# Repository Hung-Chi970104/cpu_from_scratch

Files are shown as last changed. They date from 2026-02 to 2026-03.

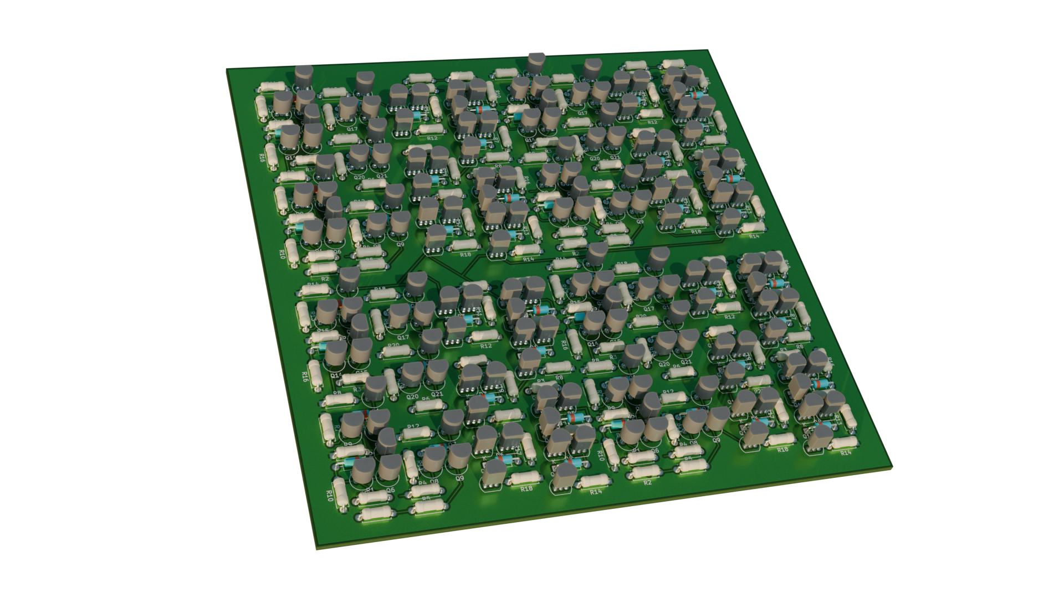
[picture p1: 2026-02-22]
assets/cpu.png

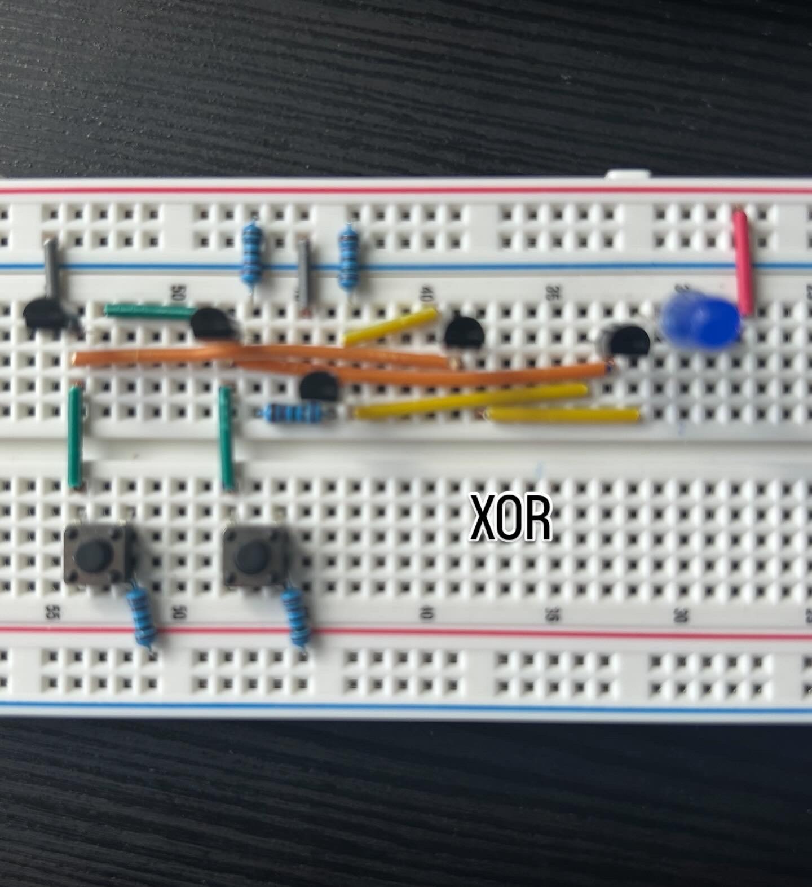
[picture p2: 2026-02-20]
assets/XOR.JPG

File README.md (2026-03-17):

## Hardware Specifications & Bill of Materials (BOM)
*** Sry this board is still in production but I'll reship it once it's delivered!!!

This project is inspired by Hyperspace Pirate: https://youtu.be/X31B1pVow1o?si=pDOqtu37fK6EBQ2z

cpu
This DIY 4-but CPU uses BJT logic to build various logic gates, while using discrete NPN transistors as saturated switches

| Component Class | Specification / Part Number | Function |
| --- | --- | --- |
| **Active Switching** | 2N3904 (NPN BJT) | Core logic gates (amplification and switching) |
| **Passive Routing** | Standard Rectifier Diodes | Signal isolation and OR-tie routing |
| **Pull-up/Pull-down** | 10kΩ Resistors | Ensuring definitive HIGH/LOW logic states |
| **Base Biasing** | 4.7kΩ Resistors | Base current limiting to prevent thermal runaway |
| **Current Limiting** | 1kΩ Resistors | Collector current limiting |

---

## Schematic Design

The architecture has both **SUM** and **CARRY (Cout)** logic using fundamental logic gates built from scratch
adder

### Logic Gate Topologies

The computational core relies on three primary gate topologies designed from discrete NPN transistors:

1. **NAND Gate:** Series-connected BJTs requiring all inputs to be HIGH to pull the output LOW
2. **NOR Gate:** Parallel-connected BJTs where any HIGH input pulls the output LOW
3. **XOR Gate:** A composite gate critical for the SUM generation

*Gate Implementation Reference:*

* [XOR Gate Schematic](https://github.com/user-attachments/assets/9e057bf3-4b33-4ee1-a783-3fd075c37234)
* [NOR Gate Schematic](https://github.com/user-attachments/assets/835cebbe-9da9-4931-9af1-0fc856e21aca)
* [NAND Gate Schematic](https://github.com/user-attachments/assets/38a2fae2-0add-45c0-82a7-d2f594ea8222)

---

## Validation Using Truth Table

The circuit has been validated against the standard 1-bit full adder truth table, successfully transitioning between all 8 states cleanly:

| Input A | Input B | Carry In (Cin) | SUM Output | Carry Out (Cout) |
| --- | --- | --- | --- | --- |
| 0 | 0 | 0 | **0** | **0** |
| 0 | 0 | 1 | **1** | **0** |
| 0 | 1 | 0 | **1** | **0** |
| 0 | 1 | 1 | **0** | **1** |
| 1 | 0 | 0 | **1** | **0** |
| 1 | 0 | 1 | **0** | **1** |
| 1 | 1 | 0 | **0** | **1** |
| 1 | 1 | 1 | **1** | **1** |

---

## Technical Challenges

To build this, I was forced to learn many things that I hadn't even seen before, such as truth table and logic gates. Truth table is the foundation of computing logic, while logic gates are the way to implement the the logic

* **Fan-Out Limitations & Signal Integrity:** Driving multiple inputs from a single output stage caused severe voltage drops. This required very careful pull-up and base resistor values to ensure subsequent transistor stages have adequate saturation current without dragging the logic HIGH state into the regions that should be low
* **XOR Current Starvation:** The initial Exclusive-OR (XOR) architecture failed due to a topology that tried to drive two separate transistor bases from a single unbuffered node. And this caused current to split in two parallel streams, preventing either transistor from fully switching

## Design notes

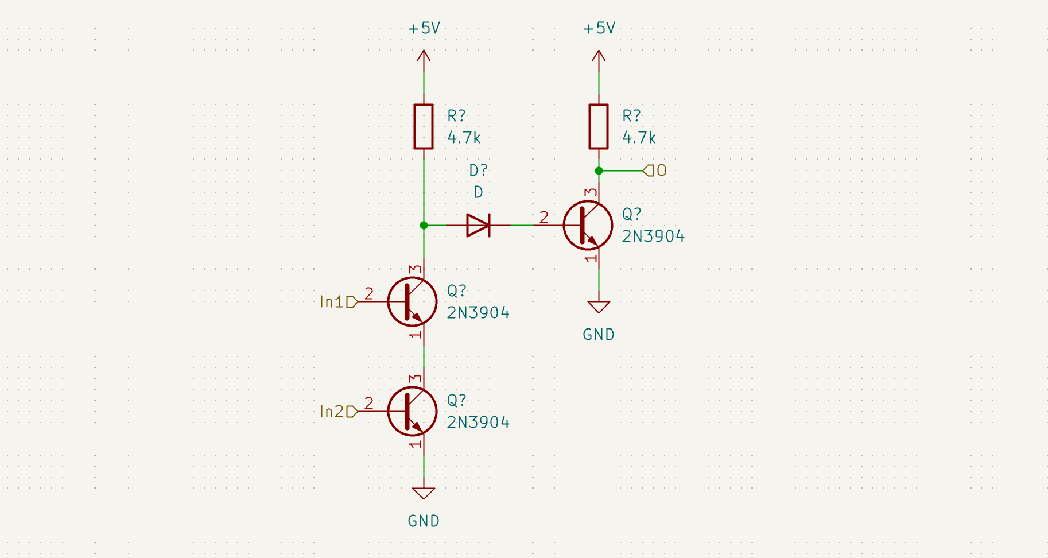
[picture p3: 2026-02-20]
assets/and.png

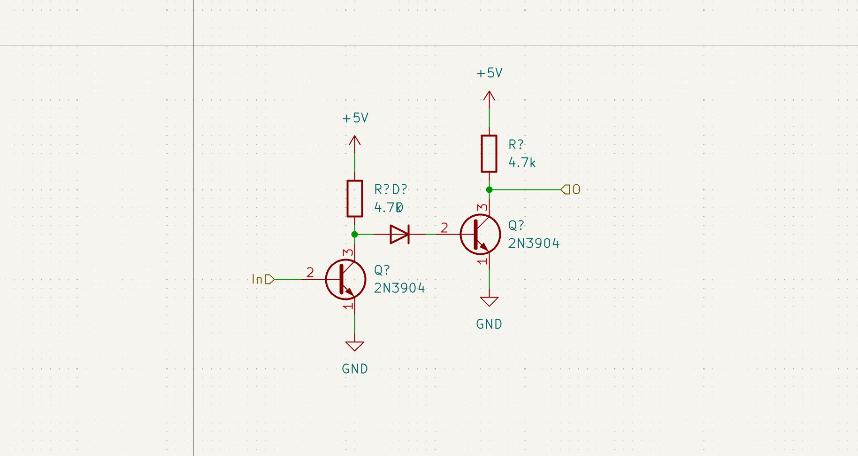
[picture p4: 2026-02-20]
assets/or.png

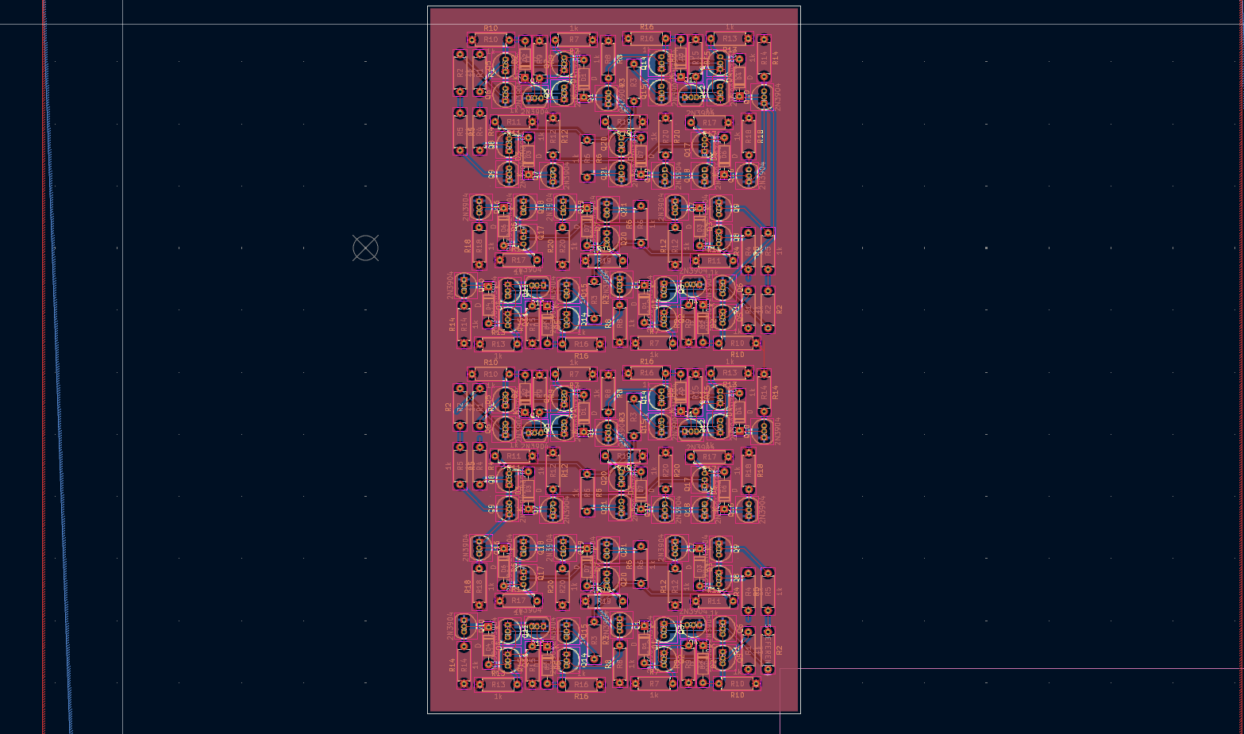
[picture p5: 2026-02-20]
assets/pcb.png

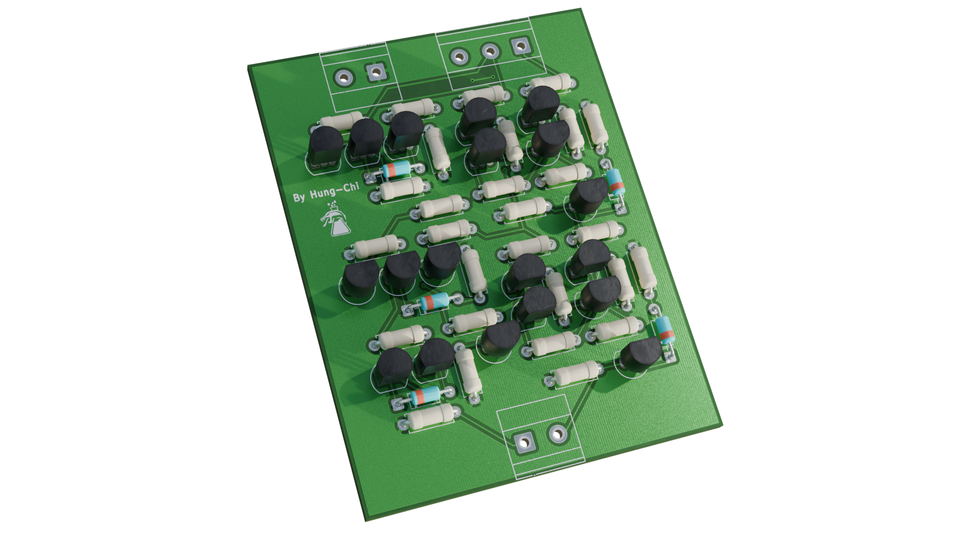
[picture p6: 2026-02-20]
assets/1_bit_adder.png

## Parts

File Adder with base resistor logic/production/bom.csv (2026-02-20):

Designator | Footprint | Quantity | Value | LCSC Part #
D1, D3, D5, D6, D8 | D_DO-35_SOD27_P7.62mm_Horizontal | 5 | D
J1, J3 | TerminalBlock_Phoenix_MKDS-1,5-2-5.08_1x02_P5.08mm_Horizontal | 2 | Screw_Terminal_01x02
J2 | TerminalBlock_Phoenix_MKDS-1,5-3-5.08_1x03_P5.08mm_Horizontal | 1 | Screw_Terminal_01x03
Q1, Q11, Q12, Q13, Q17, Q18, Q19, Q2, Q20, Q26, Q27, Q28, Q29, Q3, Q30, Q4, Q5, Q6, Q7 | TO-92_Inline | 19 | 2N3904
R1, R2, R23, R24, R25, R26, R27, R28, R29, R3, R30, R31, R32, R33, R34, R4, R43, R44, R45, R46, R47, R48, R49, R5, R50, R6, R7, R8 | R_Axial_DIN0207_L6.3mm_D2.5mm_P7.62mm_Horizontal | 28 | 4.7k

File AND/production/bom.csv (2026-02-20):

Designator | Footprint | Quantity | Value | LCSC Part #
D1 | D_DO-35_SOD27_P7.62mm_Horizontal | 1 | D
J1, J2 | PinHeader_1x03_P2.54mm_Vertical | 2 | Conn_01x03
Q1, Q2, Q3 | TO-92_Inline | 3 | 2N3904
R1, R2, R3, R4 | R_Axial_DIN0207_L6.3mm_D2.5mm_P7.62mm_Horizontal | 4 | 4.7k

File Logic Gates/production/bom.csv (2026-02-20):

Designator | Footprint | Quantity | Value | LCSC Part #
D1, D2, D3, D6 | LED_D3.0mm | 4 | LED
D4, D5 | D_DO-35_SOD27_P7.62mm_Horizontal | 2 | D
J1 | TerminalBlock_Phoenix_MKDS-1,5-2-5.08_1x02_P5.08mm_Horizontal | 1 | Screw_Terminal_01x02
Q1, Q2, Q3, Q4, Q5, Q6, Q7, Q8 | TO-92_Inline | 8 | 2N3904
R1, R10, R2, R4 | R_Axial_DIN0207_L6.3mm_D2.5mm_P7.62mm_Horizontal | 4 | 1k
R11, R12, R3, R5, R6, R7, R8, R9 | R_Axial_DIN0207_L6.3mm_D2.5mm_P7.62mm_Horizontal | 8 | 10k
SW1, SW2, SW3, SW4, SW5, SW6, SW7, SW8 | SW_PUSH_6mm | 8 | SW_Push

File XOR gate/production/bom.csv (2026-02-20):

Designator | Footprint | Quantity | Value | LCSC Part #
D1, D2 | D_DO-35_SOD27_P7.62mm_Horizontal | 2 | D
J1 | TerminalBlock_Phoenix_MKDS-1,5-3-5.08_1x03_P5.08mm_Horizontal | 1 | Screw_Terminal_01x03
Q1, Q2, Q3, Q4, Q5, Q6 | TO-92_Inline | 6 | 2N3904
R1, R2, R3, R4, R5, R6 | R_Axial_DIN0207_L6.3mm_D2.5mm_P7.62mm_Horizontal | 6 | 1k
SW1, SW2 | SW_PUSH_6mm_H4.3mm | 2 | SW_Push

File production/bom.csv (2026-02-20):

Designator | Footprint | Quantity | Value | LCSC Part #
D1_4, D1_3, D1_2, D1, D2_4, D2_3, D2_2, D2, D3_4, D3_3, D3_2, D3, D4_4, D4_3, D4_2, D4, D5_4, D5_3, D5_2, D5, D6_4, D6_3, D6_2, D6, D7_4, D7_3, D7_2, D7 | D_DO-35_SOD27_P7.62mm_Horizontal | 28 | D
Q1_4, Q1_3, Q1_2, Q1, Q10_4, Q10_3, Q10_2, Q10, Q11_4, Q11_3, Q11_2, Q11, Q12_4, Q12_3, Q12_2, Q12, Q13_4, Q13_3, Q13_2, Q13, Q14_4, Q14_3, Q14_2, Q14, Q15_4, Q15_3, Q15_2, Q15, Q16_4, Q16_3, Q16_2, Q16, Q17_4, Q17_3, Q17_2, Q17, Q18_4, Q18_3, Q18_2, Q18, Q19_4, Q19_3, Q19_2, Q19, Q2_4, Q2_3, Q2_2, Q2, Q20_4, Q20_3, Q20_2, Q20, Q21_4, Q21_3, Q21_2, Q21, Q3_4, Q3_3, Q3_2, Q3, Q4_4, Q4_3, Q4_2, Q4, Q5_4, Q5_3, Q5_2, Q5, Q6_4, Q6_3, Q6_2, Q6, Q7_4, Q7_3, Q7_2, Q7, Q8_4, Q8_3, Q8_2, Q8, Q9_4, Q9_3, Q9_2, Q9 | TO-92_Inline | 84 | 2N3904
R1_4, R1_3, R1_2, R1, R10_4, R10_3, R10_2, R10, R11_4, R11_3, R11_2, R11, R12_4, R12_3, R12_2, R12, R13_4, R13_3, R13_2, R13, R14_4, R14_3, R14_2, R14, R15_4, R15_3, R15_2, R15, R16_4, R16_3, R16_2, R16, R17_4, R17_3, R17_2, R17, R18_4, R18_3, R18_2, R18, R19_4, R19_3, R19_2, R19, R2_4, R2_3, R2_2, R2, R20_4, R20_3, R20_2, R20, R3_4, R3_3, R3_2, R3, R4_4, R4_3, R4_2, R4, R5_4, R5_3, R5_2, R5, R6_4, R6_3, R6_2, R6, R7_4, R7_3, R7_2, R7, R8_4, R8_3, R8_2, R8, R9_4, R9_3, R9_2, R9 | R_Axial_DIN0207_L6.3mm_D2.5mm_P7.62mm_Horizontal | 80 | 1k

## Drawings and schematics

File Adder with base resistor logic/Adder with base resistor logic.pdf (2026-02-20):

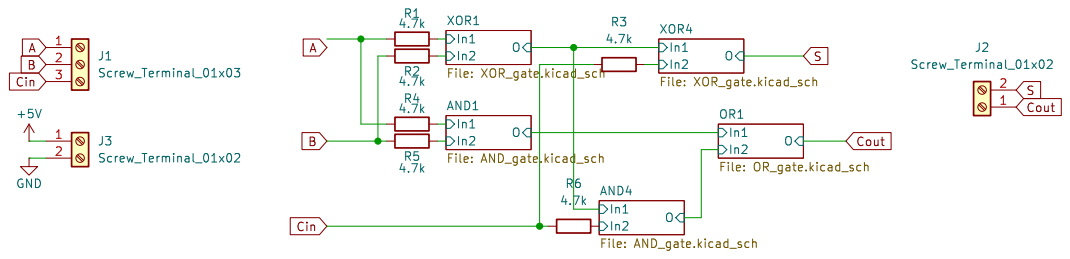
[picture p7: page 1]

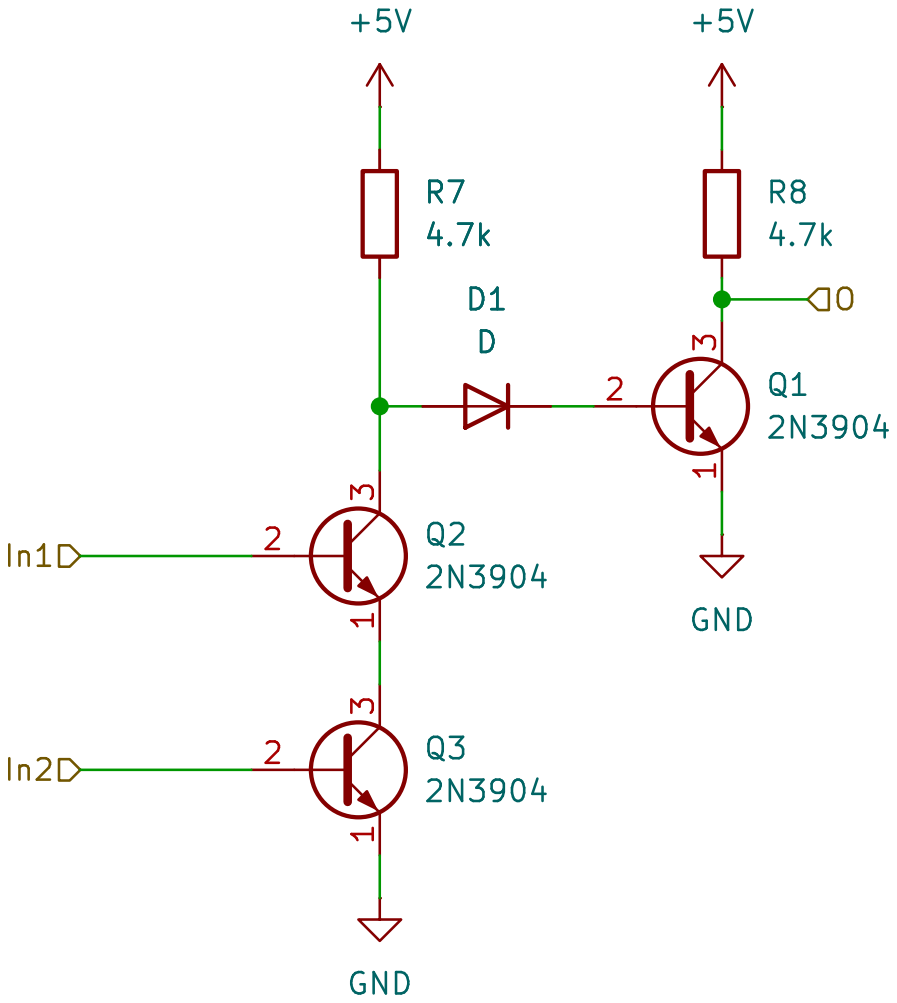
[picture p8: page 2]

Id: 3/6 Title: File: AND_gate.kicad_sch Sheet: /AND1/

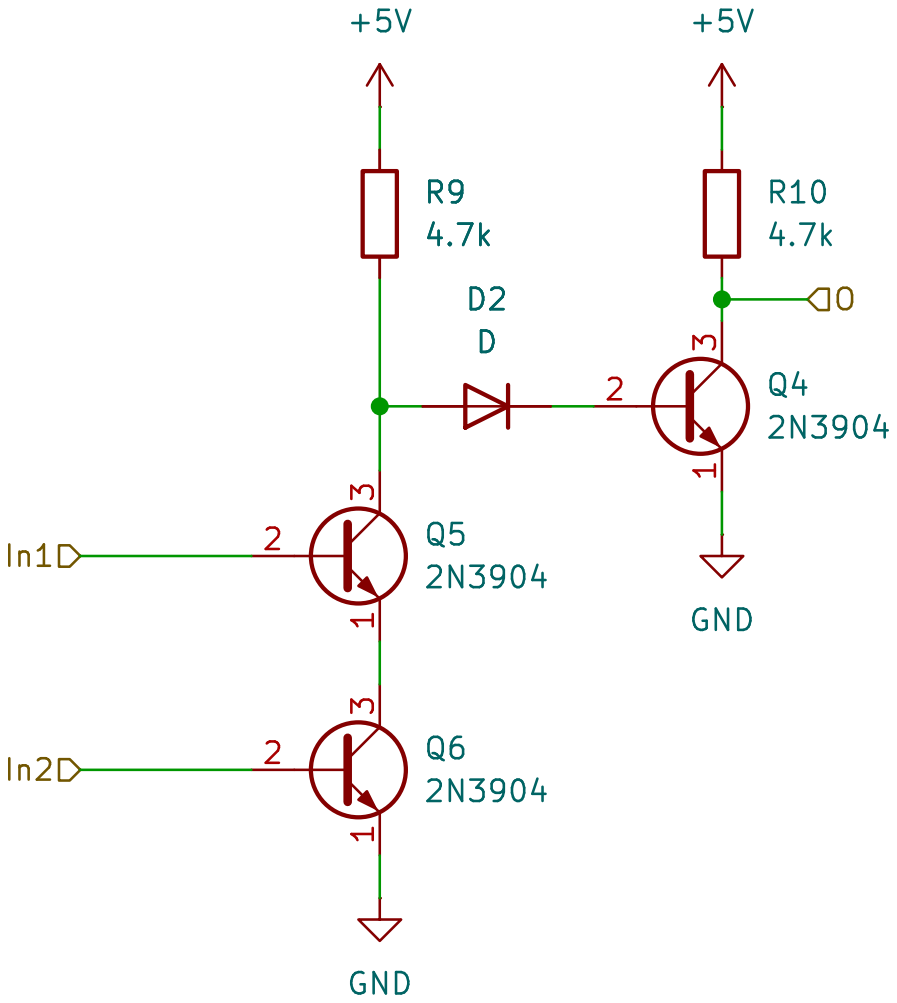
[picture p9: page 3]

Id: 5/6 Title: File: AND_gate.kicad_sch Sheet: /AND4/

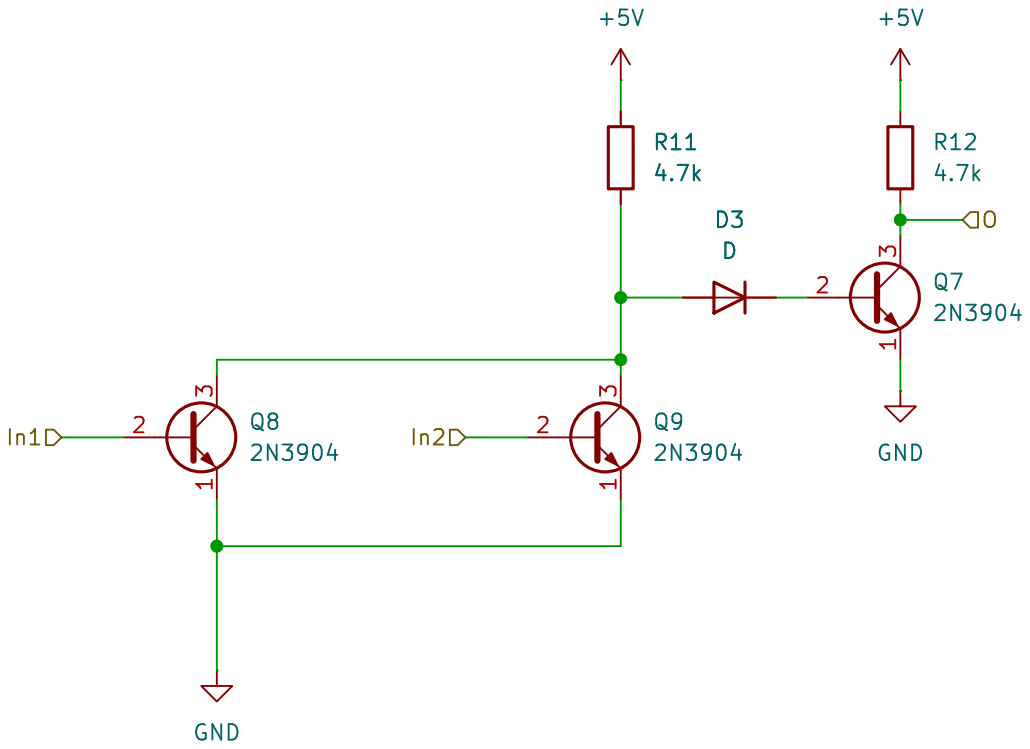
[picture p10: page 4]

Id: 8/6 Title: File: OR_gate.kicad_sch Sheet: /OR1/

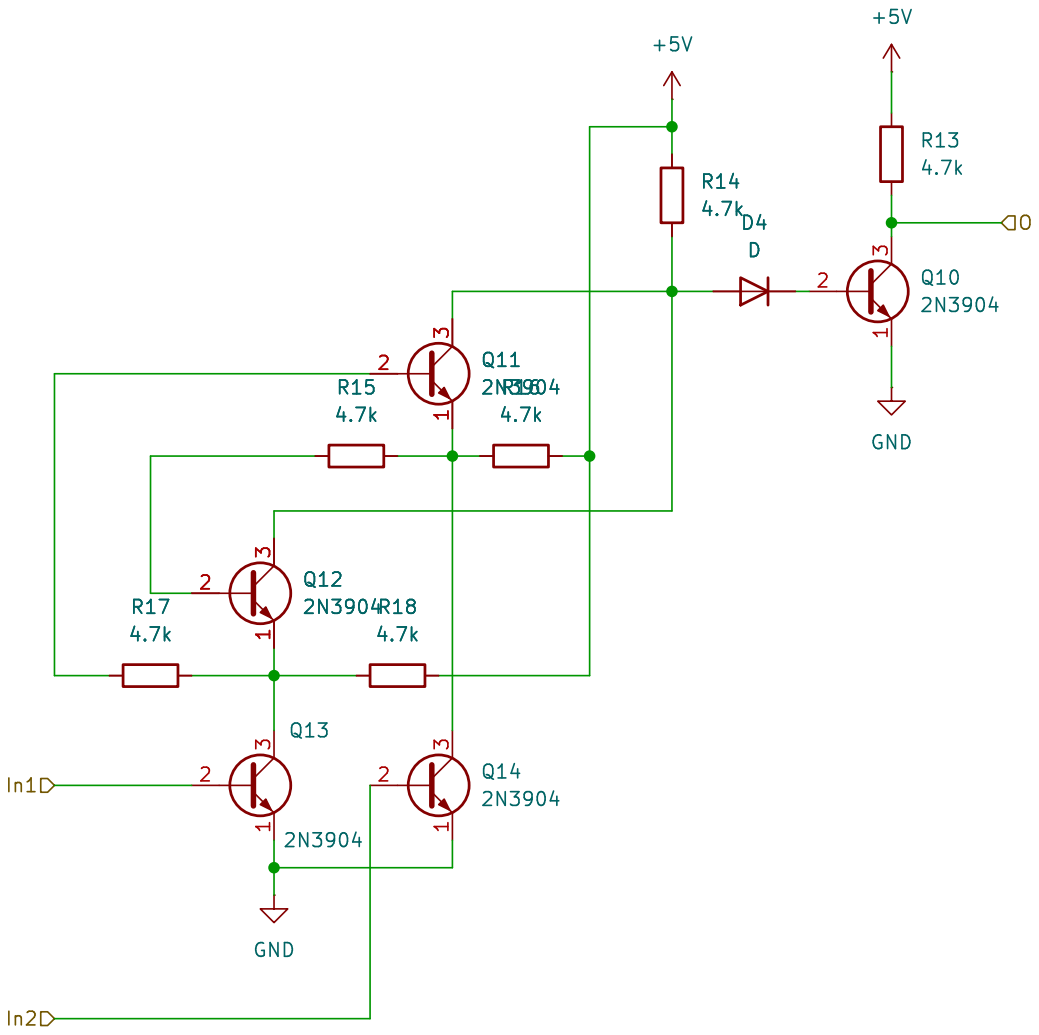
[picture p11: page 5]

Id: 10/6 Title: File: XOR_gate.kicad_sch Sheet: /XOR1/

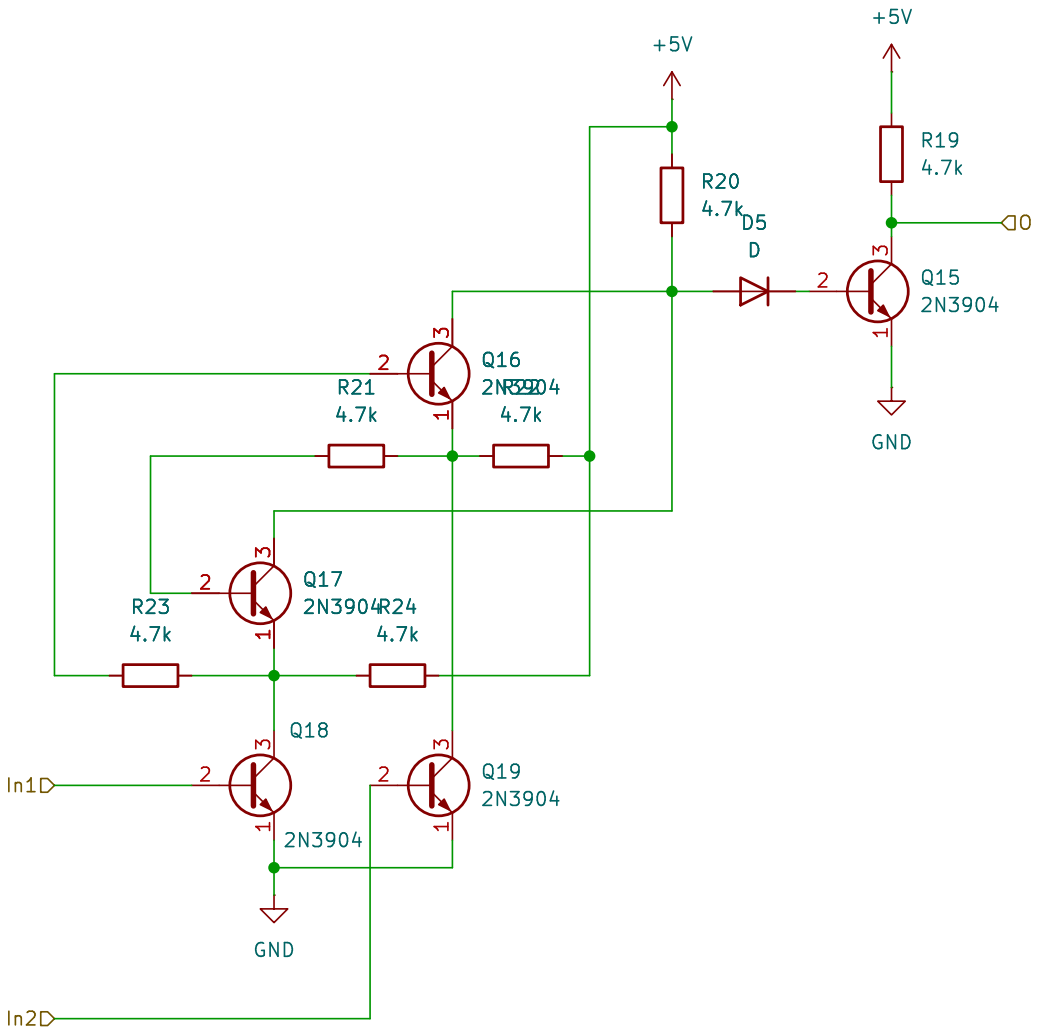
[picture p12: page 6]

Id: 11/6 Title: File: XOR_gate.kicad_sch Sheet: /XOR4/

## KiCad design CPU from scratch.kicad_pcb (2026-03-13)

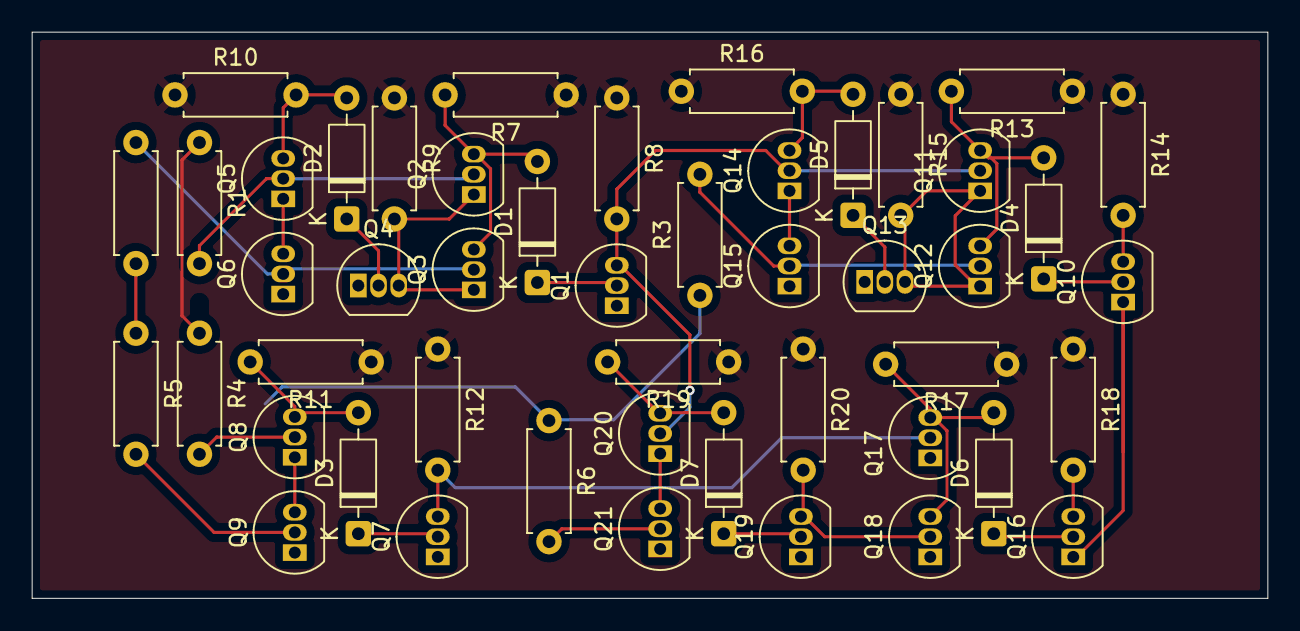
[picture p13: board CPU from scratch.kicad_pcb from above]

Board: 2 copper layers, 77.8 x 35.6 mm, 48 parts (0 on the bottom side), 36 nets.

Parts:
D1, D2, D3, D4, D5, D6, D7: D; D_DO-35_SOD27_P7.62mm_Horizontal
Q1, Q2, Q3, Q4, Q5, Q6, Q7, Q8, Q9, Q10, Q11, Q12, Q13, Q14, Q15, Q16, Q17, Q18, Q19, Q20, Q21: 2N3904; TO-92_Inline
R1, R2, R3, R4, R5, R6, R7, R8, R9, R10, R11, R12, R13, R14, R15, R16, R17, R18, R19, R20: 1k; R_Axial_DIN0207_L6.3mm_D2.5mm_P7.62mm_Horizontal

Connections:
+5V: R7.1, R8.1, R9.1, R10.1, R11.1, R12.1, R13.1, R14.1, R15.1, R16.1, R17.1, R18.1, R19.1, R20.1
/AND1/In1: Q8.2 (B), R4.2
/AND1/In2: Q9.2 (B), R5.2
/AND1/O: Q7.3 (C), Q17.2 (B), R12.2
/AND2/In1: Q1.3 (C), Q11.2 (B), Q14.2 (B), Q20.2 (B), R8.2
/AND2/In2: Q21.2 (B), R6.2
/AND2/O: Q18.2 (B), Q19.3 (C), R20.2
/XOR1/In1: Q2.2 (B), Q5.2 (B), R1.2
/XOR1/In2: Q3.2 (B), Q6.2 (B), R2.2
/XOR2/In2: Q12.2 (B), Q15.2 (B), R3.2
A: R1.1, R4.1
B: R2.1, R5.1
Cin: R3.1, R6.1
Cout: Q16.3 (C), R18.2
GND: Q1.1 (E), Q4.1 (E), Q6.1 (E), Q7.1 (E), Q9.1 (E), Q10.1 (E), Q13.1 (E), Q15.1 (E), Q16.1 (E), Q17.1 (E), Q18.1 (E), Q19.1 (E), Q21.1 (E)
unnamed: D1.2 (A), Q2.3 (C), Q3.3 (C), R7.2
unnamed: D1.1 (K), Q1.2 (B)
unnamed: D2.2 (A), Q5.3 (C), R10.2
unnamed: D2.1 (K), Q4.2 (B)
unnamed: D3.2 (A), Q8.3 (C), R11.2
unnamed: D3.1 (K), Q7.2 (B)
unnamed: D4.2 (A), Q11.3 (C), Q12.3 (C), R13.2
unnamed: D4.1 (K), Q10.2 (B)
unnamed: D5.2 (A), Q14.3 (C), R16.2
unnamed: D5.1 (K), Q13.2 (B)
unnamed: D6.2 (A), Q17.3 (C), Q18.3 (C), R17.2
unnamed: D6.1 (K), Q16.2 (B)
unnamed: D7.2 (A), Q20.3 (C), R19.2
unnamed: D7.1 (K), Q19.2 (B)
unnamed: Q2.1 (E), Q3.1 (E), Q4.3 (C), R9.2
unnamed: Q5.1 (E), Q6.3 (C)
unnamed: Q8.1 (E), Q9.3 (C)
unnamed: Q11.1 (E), Q12.1 (E), Q13.3 (C), R15.2
unnamed: Q14.1 (E), Q15.3 (C)
unnamed: Q20.1 (E), Q21.3 (C)
S: Q10.3 (C), R14.2

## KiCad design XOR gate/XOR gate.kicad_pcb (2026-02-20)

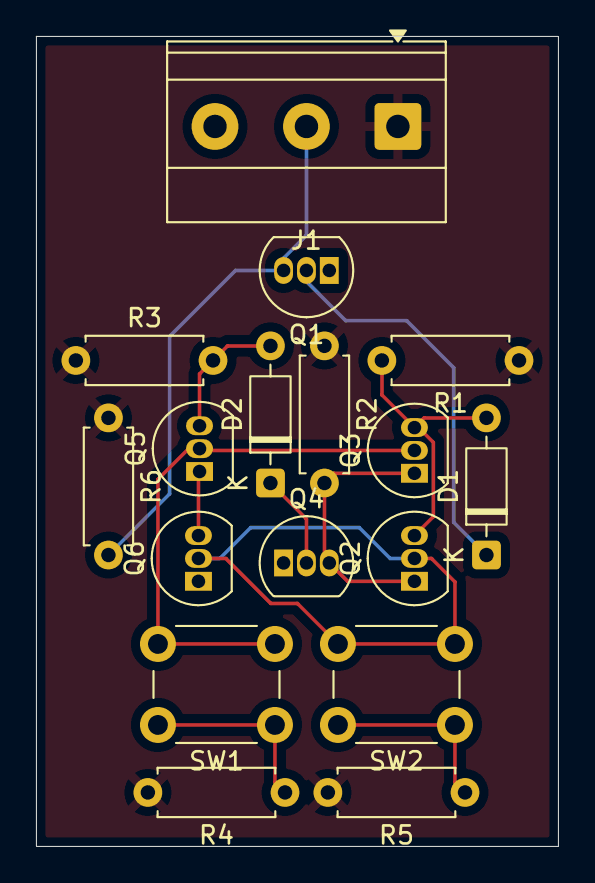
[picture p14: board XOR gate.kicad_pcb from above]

Board: 2 copper layers, 29.0 x 45.0 mm, 17 parts (0 on the bottom side), 13 nets.

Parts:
D1, D2: D; D_DO-35_SOD27_P7.62mm_Horizontal
J1: Screw_Terminal_01x03; TerminalBlock_Phoenix_MKDS-1,5-3-5.08_1x03_P5.08mm_Horizont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
Q1, Q2, Q3, Q4, Q5, Q6: 2N3904; TO-92_Inline
R1, R2, R3, R4, R5, R6: 1k; R_Axial_DIN0207_L6.3mm_D2.5mm_P7.62mm_Horizontal
SW1, SW2: SW_Push; SW_PUSH_6mm_H4.3mm

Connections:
+5V: J1.1, R1.1, R2.1, R3.1, R4.2, R5.2, R6.1
A: Q3.2 (B), Q5.2 (B), SW1.2
B: Q2.2 (B), Q6.2 (B), SW2.2
GND: J1.3, Q1.1 (E), Q4.1 (E), Q6.1 (E)
unnamed: D1.2 (A), Q2.3 (C), Q3.3 (C), R1.2
unnamed: D1.1 (K), Q1.2 (B)
unnamed: D2.2 (A), Q5.3 (C), R3.2
unnamed: D2.1 (K), Q4.2 (B)
unnamed: Q2.1 (E), Q3.1 (E), Q4.3 (C), R2.2
unnamed: Q5.1 (E), Q6.3 (C)
unnamed: R4.1, SW1.1
unnamed: R5.1, SW2.1
O: J1.2, Q1.3 (C), R6.2

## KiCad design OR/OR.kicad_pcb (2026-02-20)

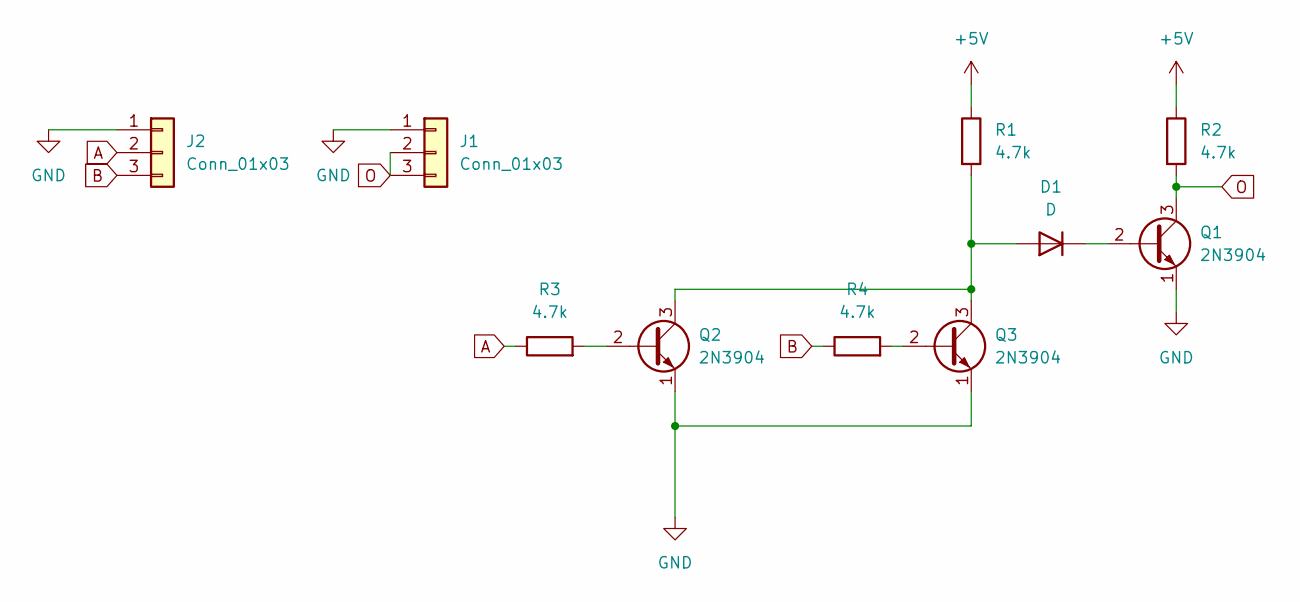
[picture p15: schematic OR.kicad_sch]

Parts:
D1: D; D_DO-35_SOD27_P7.62mm_Horizontal
J1, J2: Conn_01x03; PinHeader_1x03_P2.54mm_Vertical
Q1, Q2, Q3: 2N3904; TO-92_Inline
R1, R2, R3, R4: 4.7k; R_Axial_DIN0207_L6.3mm_D2.5mm_P7.62mm_Horizontal

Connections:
+5V: R1.1, R2.1
A: J2.2, R3.1
B: J2.3, R4.1
GND: J1.1, J2.1, Q1.1 (E), Q2.1 (E), Q3.1 (E)
unnamed: D1.2 (A), Q2.3 (C), Q3.3 (C), R1.2
unnamed: D1.1 (K), Q1.2 (B)
unnamed: Q2.2 (B), R3.2
unnamed: Q3.2 (B), R4.2
O: J1.2, J1.3, Q1.3 (C), R2.2

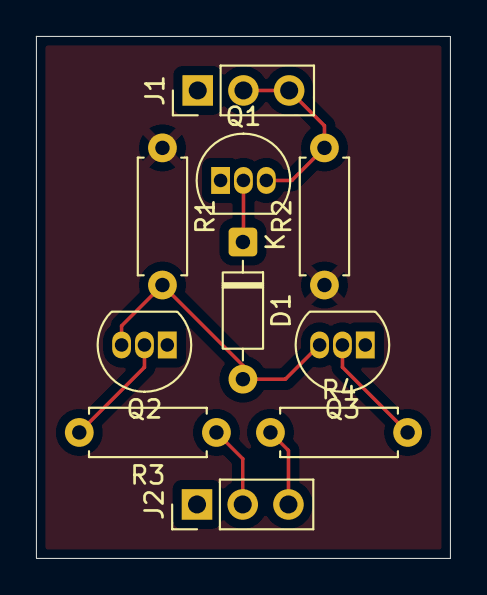
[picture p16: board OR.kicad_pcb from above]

Board: 2 copper layers, 23.0 x 29.0 mm, 10 parts (0 on the bottom side), 9 nets.

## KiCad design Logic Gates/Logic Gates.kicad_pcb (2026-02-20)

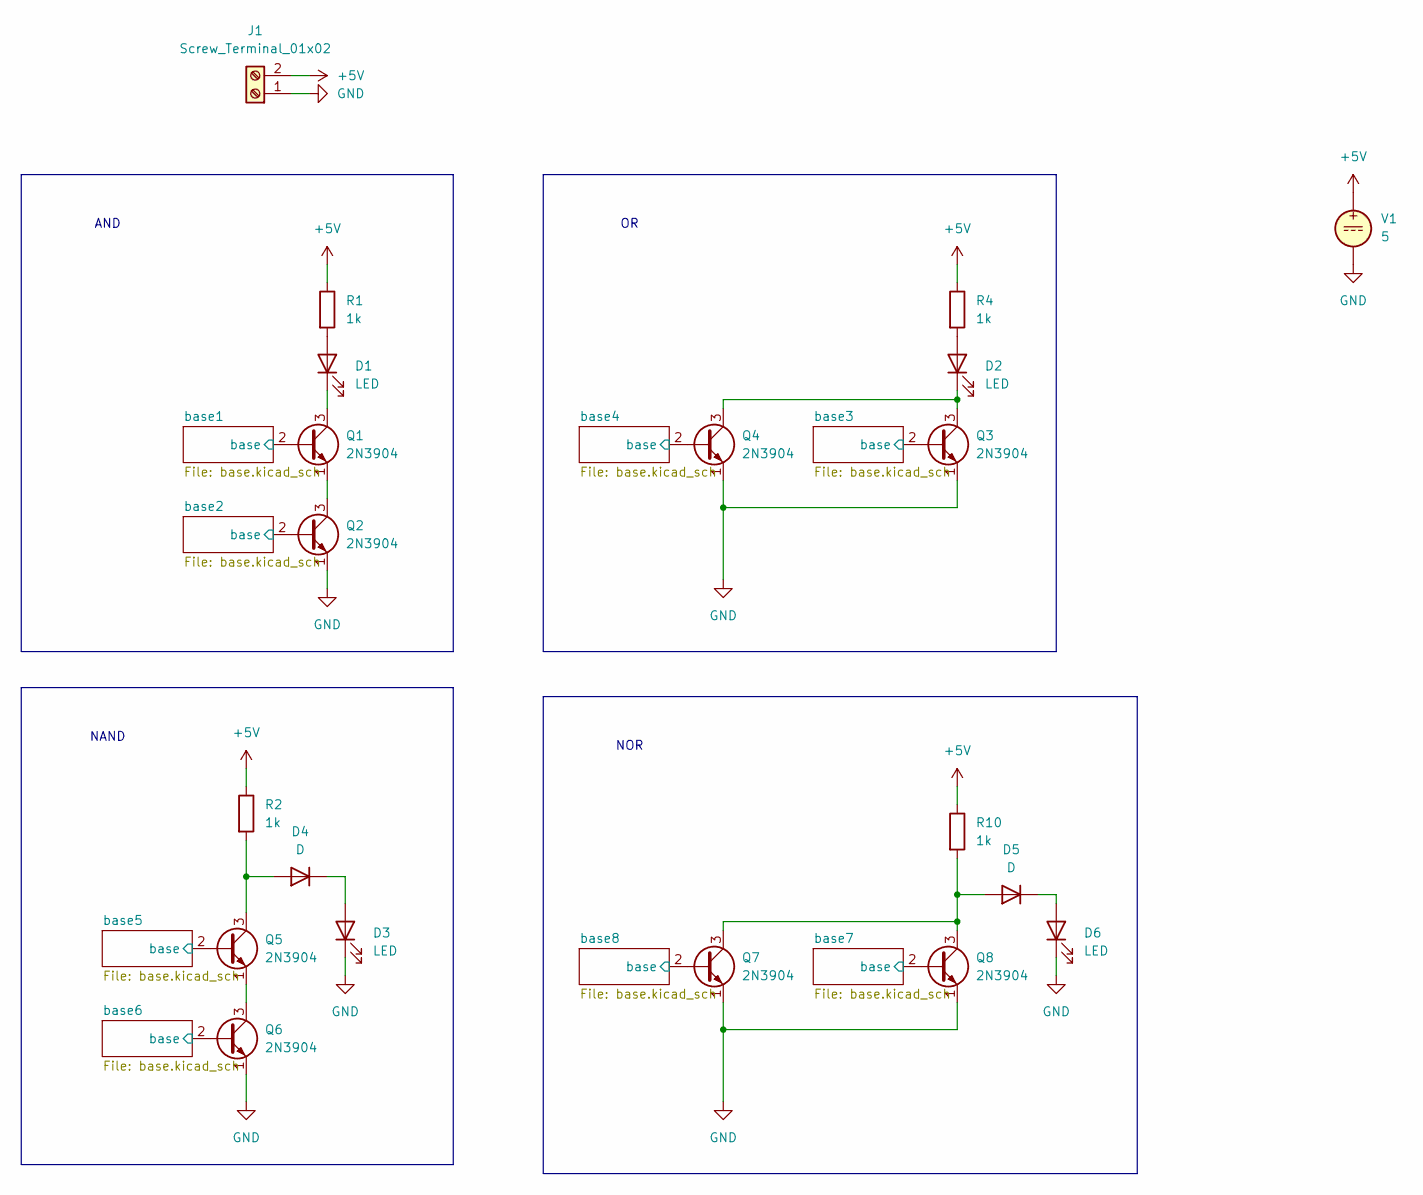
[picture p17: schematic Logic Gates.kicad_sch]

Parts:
D1, D2, D3, D6: LED; LED_D3.0mm
D4, D5: D; D_DO-35_SOD27_P7.62mm_Horizontal
J1: Screw_Terminal_01x02; TerminalBlock_Phoenix_MKDS-1,5-2-5.08_1x02_P5.08mm_Horizont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
Q1, Q2, Q3, Q4, Q5, Q6, Q7, Q8: 2N3904; TO-92_Inline
R1, R2, R4, R10: 1k; R_Axial_DIN0207_L6.3mm_D2.5mm_P7.62mm_Horizontal
V1: 5

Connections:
+5V: J1.2, R1.1, R2.1, R4.1, R10.1, V1.1; also elsewhere on the board
/base1/base: Q1.2 (B); also elsewhere on the board
/base2/base: Q2.2 (B); also elsewhere on the board
/base3/base: Q3.2 (B); also elsewhere on the board
/base4/base: Q4.2 (B); also elsewhere on the board
/base5/base: Q5.2 (B); also elsewhere on the board
/base6/base: Q6.2 (B); also elsewhere on the board
/base7/base: Q8.2 (B); also elsewhere on the board
/base8/base: Q7.2 (B); also elsewhere on the board
GND: D3.1 (K), D6.1 (K), J1.1, Q2.1 (E), Q3.1 (E), Q4.1 (E), Q6.1 (E), Q7.1 (E), Q8.1 (E), V1.2
unnamed: D1.2 (A), R1.2
unnamed: D1.1 (K), Q1.3 (C)
unnamed: D2.2 (A), R4.2
unnamed: D2.1 (K), Q3.3 (C), Q4.3 (C)
unnamed: D3.2 (A), D4.1 (K)
unnamed: D4.2 (A), Q5.3 (C), R2.2
unnamed: D5.2 (A), Q7.3 (C), Q8.3 (C), R10.2
unnamed: D5.1 (K), D6.2 (A)
unnamed: Q1.1 (E), Q2.3 (C)
unnamed: Q5.1 (E), Q6.3 (C)

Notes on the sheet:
NAND
NOR
AND

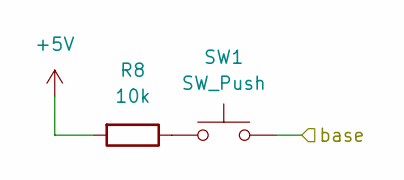
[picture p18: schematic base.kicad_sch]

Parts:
R8: 10k; R_Axial_DIN0207_L6.3mm_D2.5mm_P7.62mm_Horizontal
SW1: SW_Push; SW_PUSH_6mm

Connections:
+5V: R8.2; also elsewhere on the board
/base5/base: SW1.2; also elsewhere on the board
unnamed: R8.1, SW1.1

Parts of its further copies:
R3, R5, R6, R7, R9, R11, R12: 10k; R_Axial_DIN0207_L6.3mm_D2.5mm_P7.62mm_Horizontal
SW2, SW3, SW4, SW5, SW6, SW7, SW8: SW_Push; SW_PUSH_6mm

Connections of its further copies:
+5V: R3.2, R5.2, R6.2, R7.2, R9.2, R11.2, R12.2; also elsewhere on the board
/base1/base: SW2.2; also elsewhere on the board
/base2/base: SW3.2; also elsewhere on the board
/base3/base: SW4.2; also elsewhere on the board
/base4/base: SW5.2; also elsewhere on the board
/base6/base: SW6.2; also elsewhere on the board
/base7/base: SW7.2; also elsewhere on the board
/base8/base: SW8.2; also elsewhere on the board
unnamed: R3.1, SW2.1
unnamed: R5.1, SW3.1
unnamed: R6.1, SW4.1
unnamed: R7.1, SW5.1
unnamed: R9.1, SW6.1
unnamed: R11.1, SW7.1
unnamed: R12.1, SW8.1

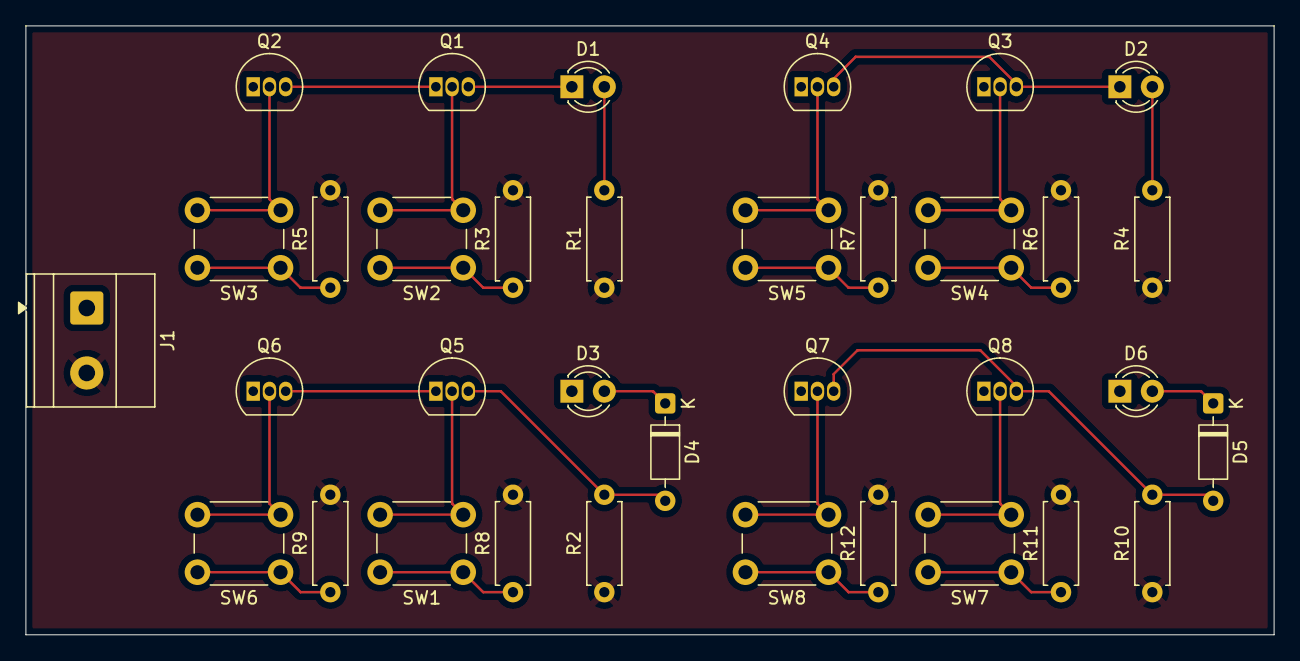
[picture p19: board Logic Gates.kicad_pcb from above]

Board: 2 copper layers, 97.6 x 47.6 mm, 35 parts (0 on the bottom side), 28 nets.

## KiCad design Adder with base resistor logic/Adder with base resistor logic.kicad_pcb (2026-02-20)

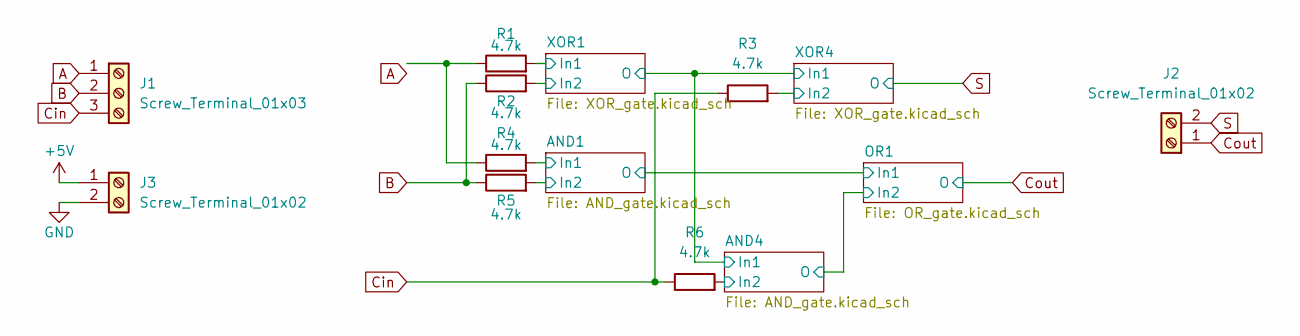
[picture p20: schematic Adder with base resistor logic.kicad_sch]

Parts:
J1: Screw_Terminal_01x03; TerminalBlock_Phoenix_MKDS-1,5-3-5.08_1x03_P5.08mm_Horizont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
J2, J3: Screw_Terminal_01x02; TerminalBlock_Phoenix_MKDS-1,5-2-5.08_1x02_P5.08mm_Horizont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
R1, R2, R3, R4, R5, R6: 4.7k; R_Axial_DIN0207_L6.3mm_D2.5mm_P7.62mm_Horizontal

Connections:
+5V: J3.1; also elsewhere on the board
/AND1/In1: R4.2; also elsewhere on the board
/AND1/In2: R5.2; also elsewhere on the board
/AND4/In2: R6.2; also elsewhere on the board
/XOR1/In1: R1.2; also elsewhere on the board
/XOR1/In2: R2.2; also elsewhere on the board
/XOR4/In2: R3.2; also elsewhere on the board
A: J1.1
B: J1.2, R2.1, R5.1
Cin: J1.3, R3.1, R6.1
Cout: J2.1; also elsewhere on the board
GND: J3.2; also elsewhere on the board
unnamed: R1.1, R4.1
S: J2.2; also elsewhere on the board

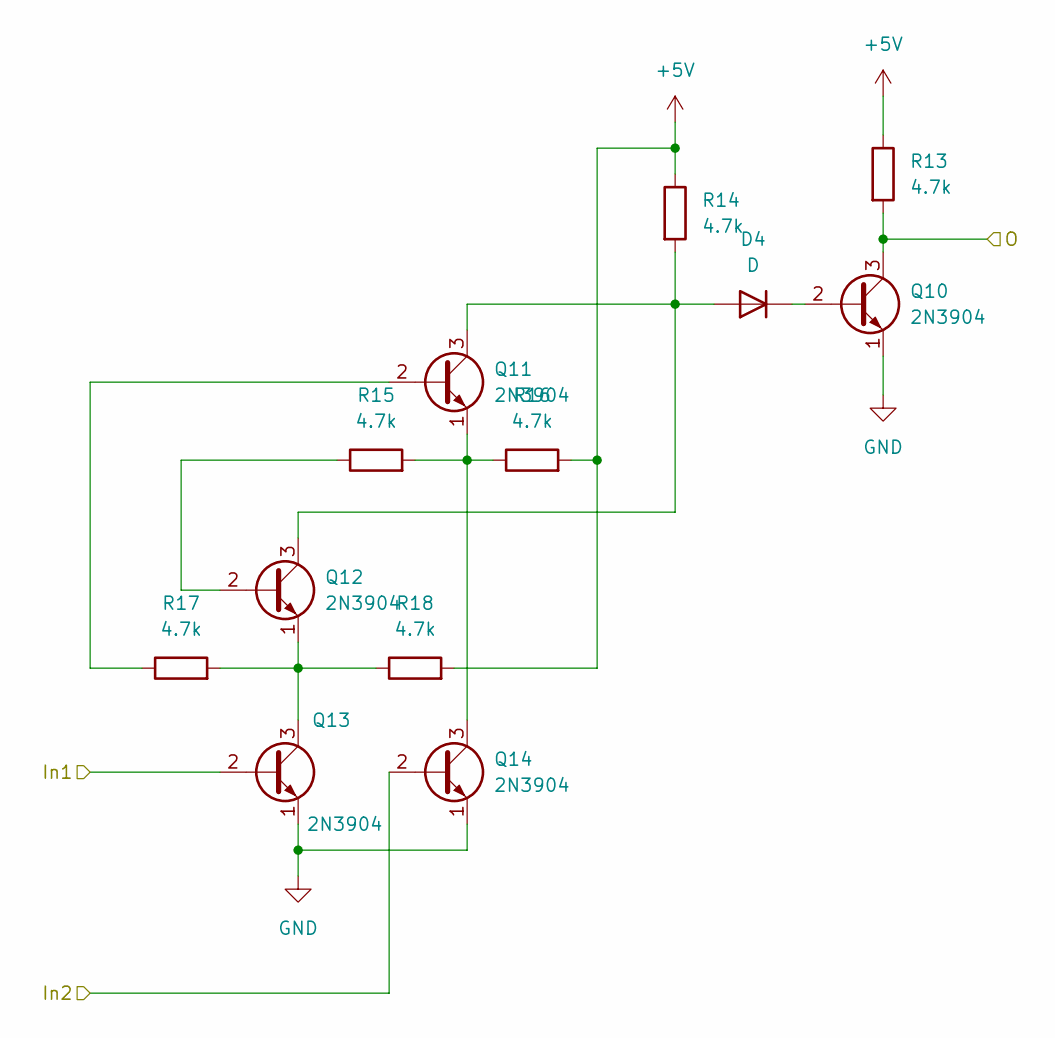
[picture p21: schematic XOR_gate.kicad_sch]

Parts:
D4: D; D_DO-35_SOD27_P7.62mm_Horizontal
Q10, Q11, Q12, Q13, Q14: 2N3904; TO-92_Inline
R13, R14, R15, R16, R17, R18: 4.7k; R_Axial_DIN0207_L6.3mm_D2.5mm_P7.62mm_Horizontal

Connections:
+5V: R13.1, R14.1, R16.2, R18.2; also elsewhere on the board
/AND4/In1: Q10.3 (C), R13.2; also elsewhere on the board
/XOR1/In1: Q13.2 (B); also elsewhere on the board
/XOR1/In2: Q14.2 (B); also elsewhere on the board
GND: Q10.1 (E), Q13.1 (E), Q14.1 (E); also elsewhere on the board
unnamed: D4.2 (A), Q11.3 (C), Q12.3 (C), R14.2
unnamed: D4.1 (K), Q10.2 (B)
unnamed: Q11.2 (B), R17.1
unnamed: Q11.1 (E), Q14.3 (C), R15.2, R16.1
unnamed: Q12.2 (B), R15.1
unnamed: Q12.1 (E), Q13.3 (C), R17.2, R18.1

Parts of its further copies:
D5: D; D_DO-35_SOD27_P7.62mm_Horizontal
Q15, Q16, Q17, Q18, Q19: 2N3904; TO-92_Inline
R19, R20, R21, R22, R23, R24: 4.7k; R_Axial_DIN0207_L6.3mm_D2.5mm_P7.62mm_Horizontal

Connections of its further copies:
+5V: R19.1, R20.1, R22.2, R24.2; also elsewhere on the board
/AND4/In1: Q18.2 (B); also elsewhere on the board
/XOR4/In2: Q19.2 (B); also elsewhere on the board
GND: Q15.1 (E), Q18.1 (E), Q19.1 (E); also elsewhere on the board
unnamed: D5.2 (A), Q16.3 (C), Q17.3 (C), R20.2
unnamed: D5.1 (K), Q15.2 (B)
unnamed: Q16.2 (B), R23.1
unnamed: Q16.1 (E), Q19.3 (C), R21.2, R22.1
unnamed: Q17.2 (B), R21.1
unnamed: Q17.1 (E), Q18.3 (C), R23.2, R24.1
S: Q15.3 (C), R19.2; also elsewhere on the board

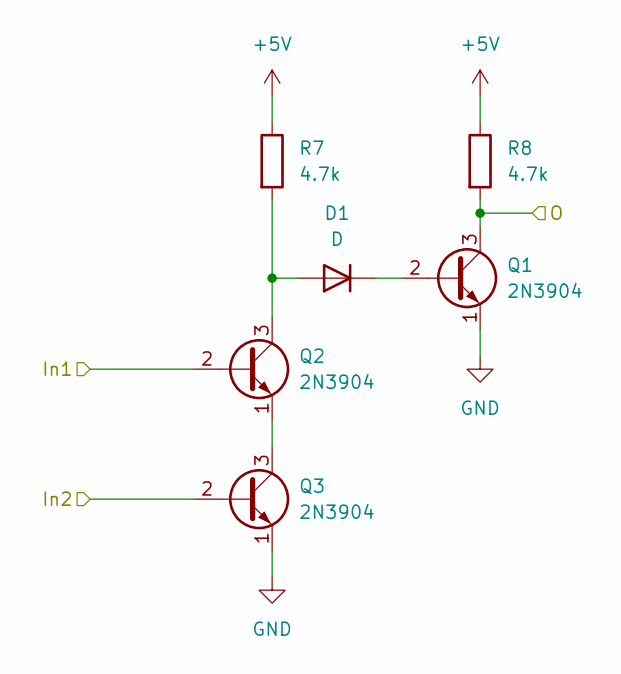
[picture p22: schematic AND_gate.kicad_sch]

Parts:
D1: D; D_DO-35_SOD27_P7.62mm_Horizontal
Q1, Q2, Q3: 2N3904; TO-92_Inline
R7, R8: 4.7k; R_Axial_DIN0207_L6.3mm_D2.5mm_P7.62mm_Horizontal

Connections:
+5V: R7.1, R8.1; also elsewhere on the board
/AND1/In1: Q2.2 (B); also elsewhere on the board
/AND1/In2: Q3.2 (B); also elsewhere on the board
/AND1/O: Q1.3 (C), R8.2; also elsewhere on the board
GND: Q1.1 (E), Q3.1 (E); also elsewhere on the board
unnamed: D1.2 (A), Q2.3 (C), R7.2
unnamed: D1.1 (K), Q1.2 (B)
unnamed: Q2.1 (E), Q3.3 (C)

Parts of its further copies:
D2: D; D_DO-35_SOD27_P7.62mm_Horizontal
Q4, Q5, Q6: 2N3904; TO-92_Inline
R9, R10: 4.7k; R_Axial_DIN0207_L6.3mm_D2.5mm_P7.62mm_Horizontal

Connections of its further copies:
+5V: R9.1, R10.1; also elsewhere on the board
/AND4/In1: Q5.2 (B); also elsewhere on the board
/AND4/In2: Q6.2 (B); also elsewhere on the board
/AND4/O: Q4.3 (C), R10.2; also elsewhere on the board
GND: Q4.1 (E), Q6.1 (E); also elsewhere on the board
unnamed: D2.2 (A), Q5.3 (C), R9.2
unnamed: D2.1 (K), Q4.2 (B)
unnamed: Q5.1 (E), Q6.3 (C)

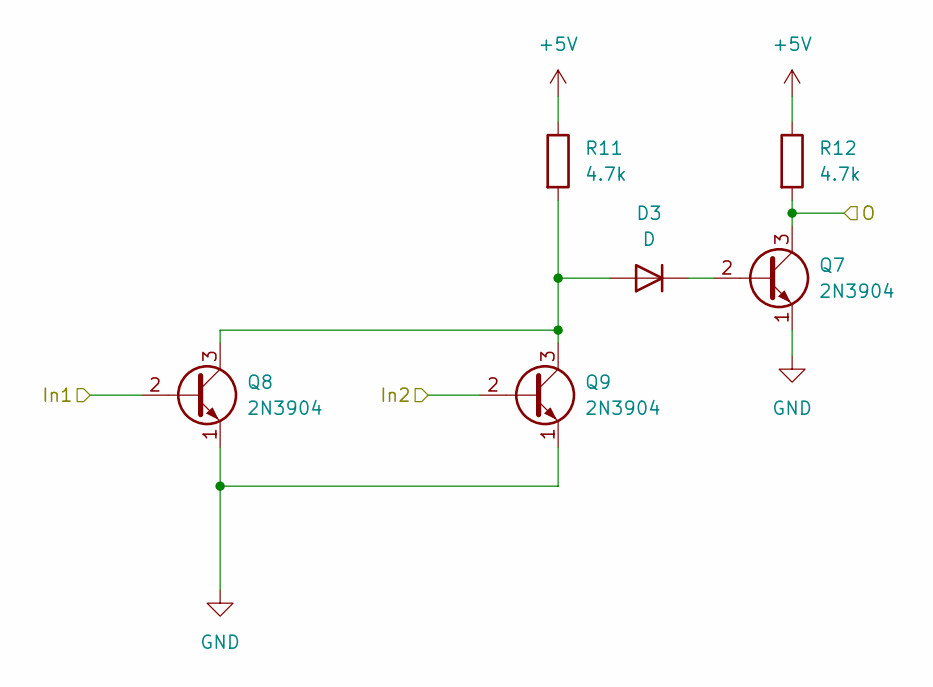
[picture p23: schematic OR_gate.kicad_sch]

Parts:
D3: D; D_DO-35_SOD27_P7.62mm_Horizontal
Q7, Q8, Q9: 2N3904; TO-92_Inline
R11, R12: 4.7k; R_Axial_DIN0207_L6.3mm_D2.5mm_P7.62mm_Horizontal

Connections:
+5V: R11.1, R12.1; also elsewhere on the board
/AND1/O: Q8.2 (B); also elsewhere on the board
/AND4/O: Q9.2 (B); also elsewhere on the board
Cout: Q7.3 (C), R12.2; also elsewhere on the board
GND: Q7.1 (E), Q8.1 (E), Q9.1 (E); also elsewhere on the board
unnamed: D3.2 (A), Q8.3 (C), Q9.3 (C), R11.2
unnamed: D3.1 (K), Q7.2 (B)

Board: 2 copper layers, 51 parts (0 on the bottom side), 36 nets, no tracks yet.

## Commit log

2026-03-13 Update PCB
    [CPU from scratch.kicad_pcb]
2026-03-17 Update section title from 'Schematic & Architectural Design' to 'Schematic Design'
